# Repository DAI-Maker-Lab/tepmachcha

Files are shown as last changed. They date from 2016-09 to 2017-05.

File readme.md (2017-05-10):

# Tepmachcha

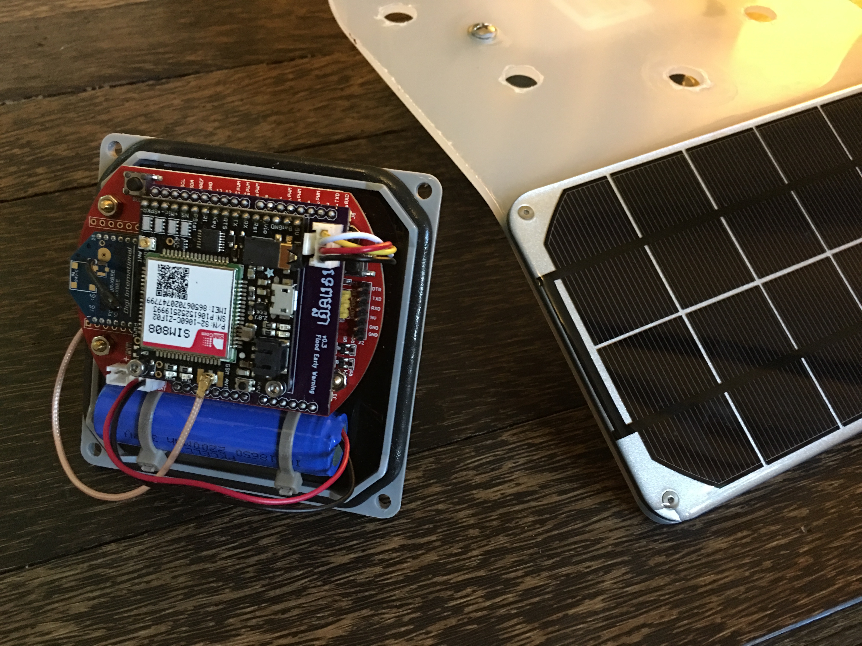
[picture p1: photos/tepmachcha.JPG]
tepmacha


## Flood Early Warning Using Sonar and IVR
Tepmachcha is an open source sonar stream gauge designed to give early warning of flood conditions to residents in vulnerable areas. When a flood condition is detected, Tepmachcha triggers a call with a voice recording via the RapidPro interactive voice response (IVR) system. It also records water levels at regular intervals for later analysis of flooding patterns or to inform more complex hydrological analysis. 

Tepmachcha was designed at the [DAI Maker Lab](http://dai.com/makerlab) in collaboration with [People in Need Cambodia](https://www.clovekvtisni.cz/en/humanitary-aid/country/cambodia) with funding from USAID's [Development Innovations](http://www.development-innovations.org/) project, People in Need, and DAI. It is a fork of the [*Hidrosónico* sonar stream gauge](https://github.com/DAI-Maker-Lab/hidrosonico) piloted by DAI in Honduras as part of the [USAID Proparque](http://en.usaid-proparque.org/) project. It is released under the MIT License.

## Matsya/Tepmachcha
The world-reknowned friezes at Angkor Wat depict scenes from Cambodian history and Hindu mythology, including the [tale of the god Vishnu appearing in the form of a fish to warn mankind of a catastrophic flood](https://en.wikipedia.org/wiki/Matsya). This fish avatar, known in Sanskrit as "Matsya", is called "Tepmachcha" in Khmer, and is the namesake of the project.

## What Tepmachcha Does: The Short Story
Tepmachcha uses sonar to read the level of water in a river, stream, or canal, at regular intervals determined by the user. It uses a cellular data connection to report that level to an internet server. If Tepmachcha detects water level in excess of yellow or red alert limits set by the user, it sends an HTTP POST request that triggers an instance of the RapidPro IVR system to make a voice call that warns users in the affected area(s). Certain operational commands can be sent to the unit by SMS.

## The DAI Maker Lab Design Approach
The DAI Maker Lab leverages emerging tools and approaches associated with the maker movement to build devices and capacity that empower people in developing countries to apply technology to problems. The goal is hardware that can be locally built, repaired, maintained and extended. Toward that end, DAI Maker Lab designs:

* Are always released as open source.
* Utilize off-the-shelf parts when possible.
* Utilize open source hardware when possible, so that discontinuted components can be later recreated or replaced if necessary. 
* Prefer well-documented component hardware, and hardware with an existing community of development and support, to maximize value to end users.
* Prefer transparency to non-expert users over optimal computational or engineering design.

## Hardware
The bill of materials for Tepmachcha includes:

* The [**Seeeduino Stalker v3.0**](http://www.seeedstudio.com/wiki/Seeeduino-Stalker_v3) Arduino-compatible microcontroller board. The Stalker is not the most commonly available Arduino-compatible board, and to be honest, the English documentation -- while much improved over the last year -- is not perfect. But its optimization for low-power operation; inclusion of a solar battery charging circuit, real-time clock (RTC), and XBee socket; and reasonable price make it a good choice for Tepmachcha. 
* The [**Adafruit FONA 808**](https://learn.adafruit.com/adafruit-fona-808-cellular-plus-gps-breakout/overview) cellular breakout board. There are less expensive GSM boards on the market, but Adafruit's standard of documentation, support, and community are difficult to beat. We use the 808 rather than the slightly cheaper 800 because it supports SSL, which RapidPro requires.
* The [**Maxbotix MB7363 HRXL-MaxSonar-WRLS**](http://www.maxbotix.com/Ultrasonic_Sensors/MB7363.htm) sonar. 
* [A simple custom PCB](https://oshpark.com/shared_projects/et6LqUSw) to connect the various parts. This is optional but keeps everything neat and connected inside the enclosure.
* An [**XBee XB24-AWI-001**](http://www.digikey.com/product-detail/en/digi-international/XB24-AWI-001/XB24-AWI-001-ND/935965) radio enables wireless reprogramming in proximity to the unit. Because the units are generally installed in places that are not easy to get to, taking them down and opening them up to flash updated firmware is a real pain. But the XBee can be tempremental; it costs money, uses power and there is a fair amount of code supporting its use, so a non-crazy person might elect to exclude it.
* A **power subsystem**. The Stalker has a charging circuit, but a [LiPo battery](https://www.adafruit.com/products/1781) and a [solar panel](https://www.adafruit.com/products/500) are required; the solar panel will probably have to be spliced onto a [JST-PH 2mm connector](https://www.adafruit.com/products/261) to plug into the Stalker.

The complete bill of materials is included in the repository.

## Libraries
Tepmachcha uses:

* The [Adafruit FONA library](https://github.com/adafruit/Adafruit_FONA_Library).
* [Seeed Studio's DS1337](https://github.com/Seeed-Studio/Sketch_Stalker_V3_1/blob/master/libraries/DS1337/DS1337.h) real time clock library.
* The [Sleep_n0m1](https://github.com/n0m1/Sleep_n0m1) sleep library.
* SoftwareSerial
* Wire

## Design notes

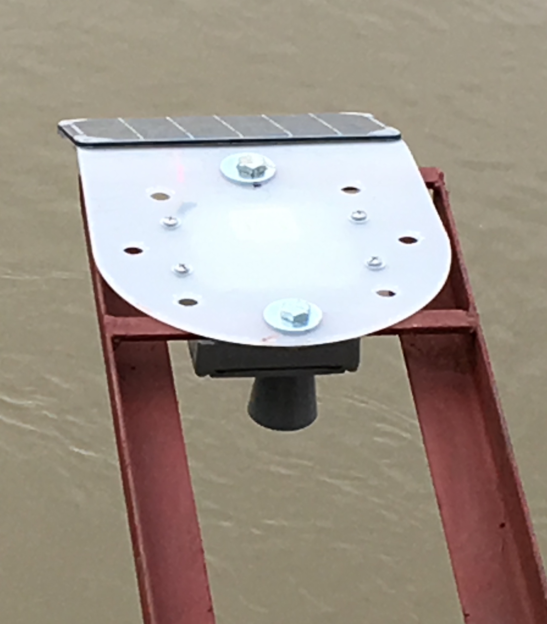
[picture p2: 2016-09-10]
photos/mount_example3.JPG

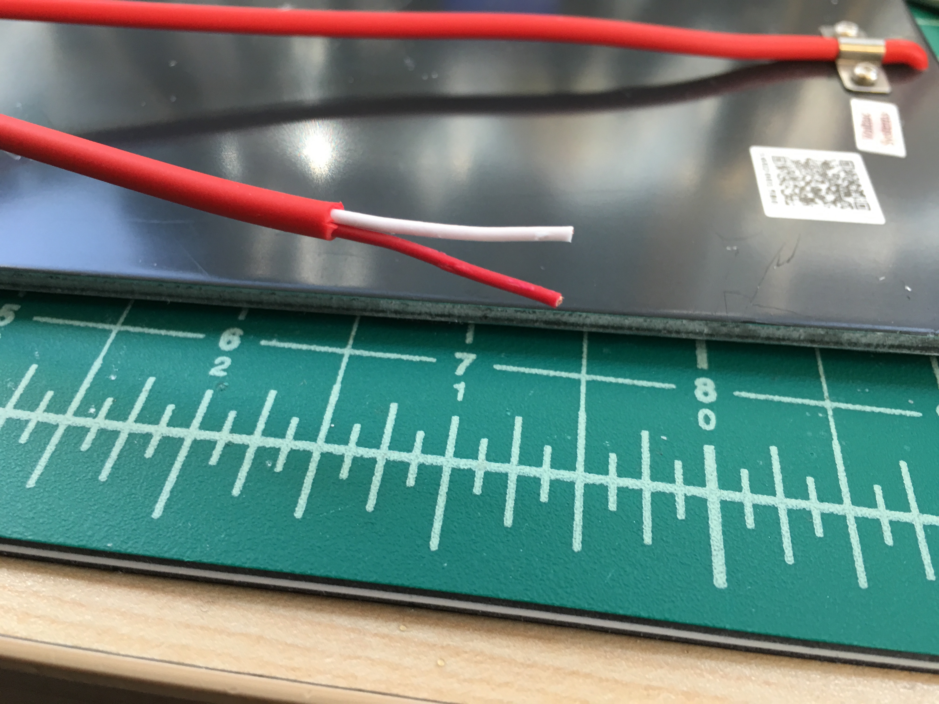
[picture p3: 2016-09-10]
photos/expose_wires.JPG

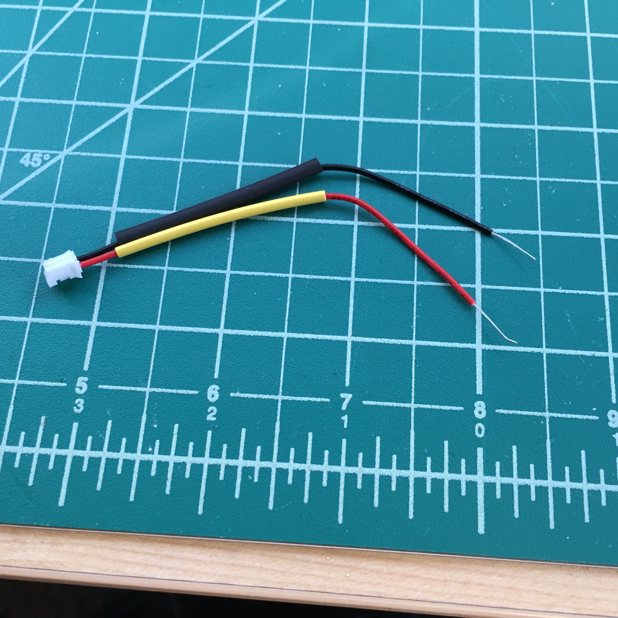
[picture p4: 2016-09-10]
photos/jst.JPG

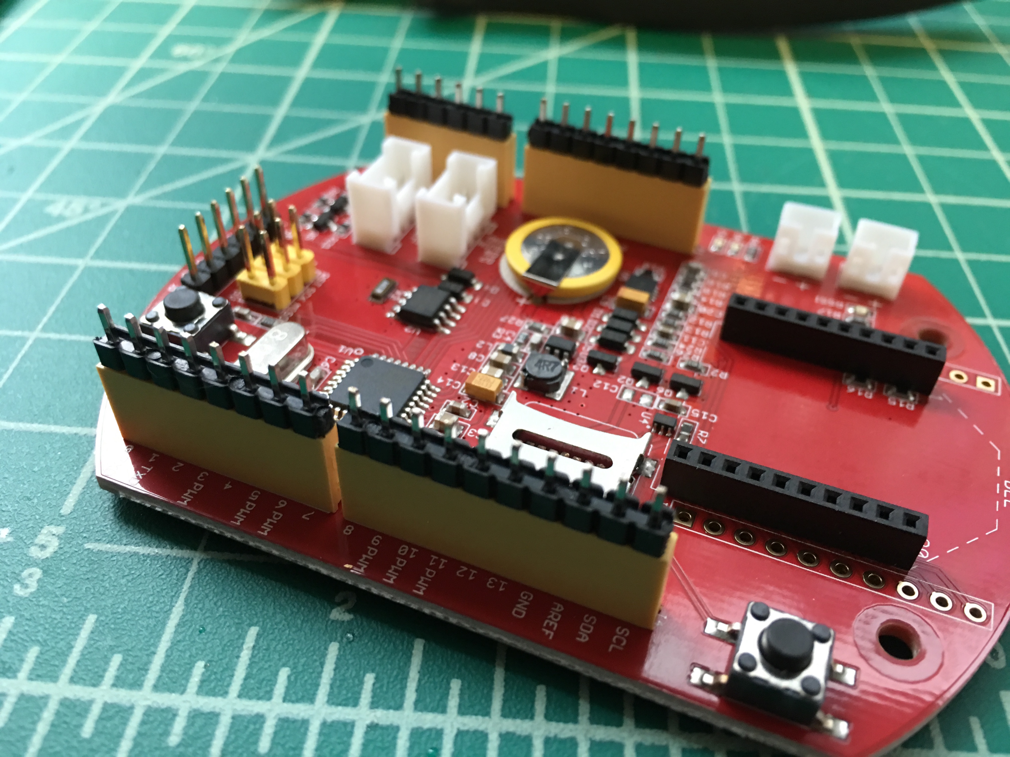
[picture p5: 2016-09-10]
photos/stalker-headers.JPG

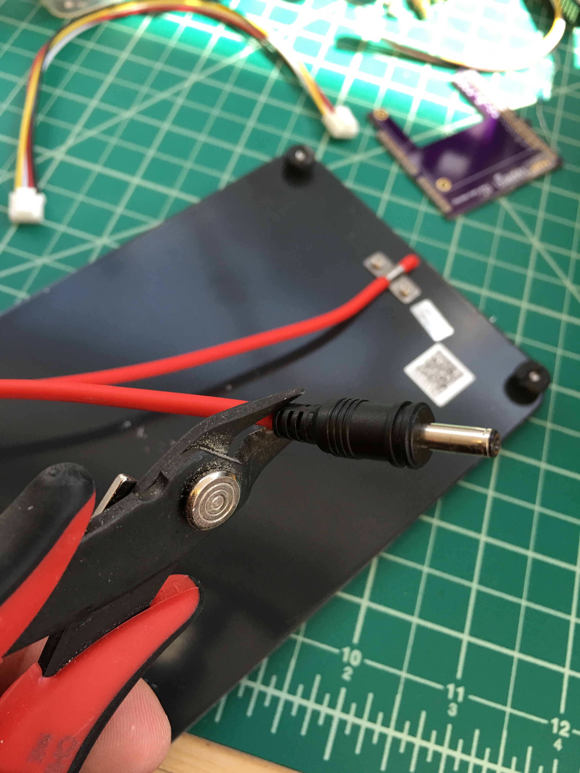
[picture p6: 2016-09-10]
photos/cut_barrel.JPG

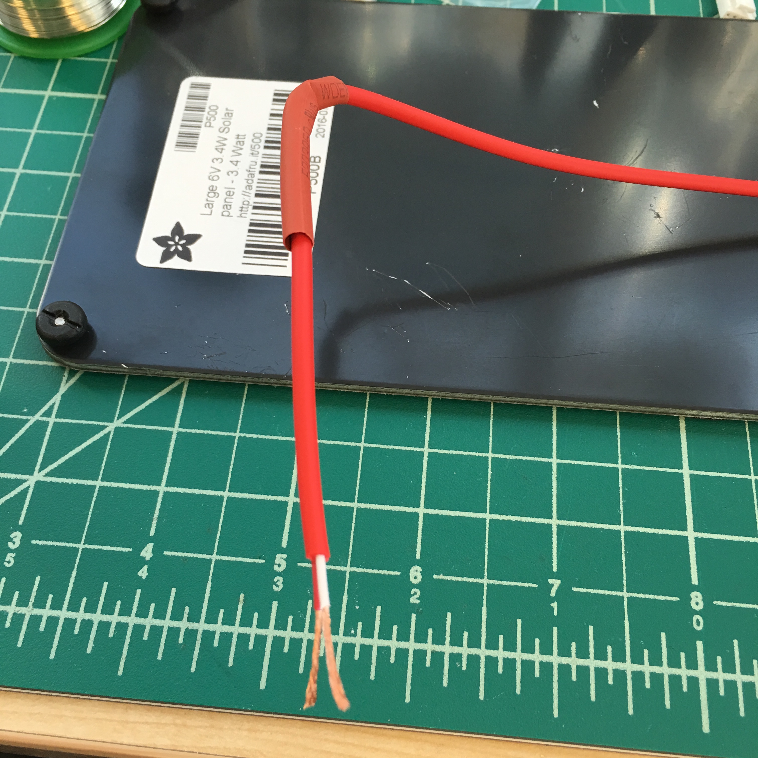
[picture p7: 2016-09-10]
photos/stripped_solar_heatshrink.JPG

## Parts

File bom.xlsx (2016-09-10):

Tepmachcha Bill of Materials
Part | Manufacturer Part Number | Vendor Information | Unit Cost | Pieces per Unit | Total Cost
3D Printed Frame | n/a | Custom (PLA) | $0.36 | 1 | $0.36
Heatshrink tubing | Generic | https://smile.amazon.com/gp/product/B00OZSL8UE | $0.02 | 2 | $0.04
Adafruit FONA 808 uFL | 2542 | https://www.adafruit.com/products/2542 | $49.95 | 1 | $49.95
M2.5 socket cap screw | 91292A012 | http://www.mcmaster.com/mv1472829955/#catalog/91292A012 | $0.05 | 2 | $0.10
Unthreaded spacer for M2.5 screw size | 94669A094 | http://www.mcmaster.com/mv1472829955/#catalog/94669A094 | $0.35 | 2 | $0.70
M2.5 nut | 90591A113 | http://www.mcmaster.com/mv1472829955/#catalog/90591A113 | $0.01 | 2 | $0.02
Carlon 4"x2" PVC junction box | E989NNJ-CAR | http://www.homedepot.com/p/Carlon-4-in-x-2-in-Junction-Box-E989NNJ-CAR/100404097 | $6.88 | 1 | $6.88
Grove 4-pin Female Jumper to Grove 4-pin Conversion Cable | 110990028 | http://www.seeedstudio.com/depot/Grove-4-pin-Female-Jumper-to-Grove-4-pin-Conversion-Cable-5-PCs-per-PAck-p-1020.html | $0.78 | 1 | $0.78
LiPo battery | 1781 | https://www.adafruit.com/products/1781 | $9.95 | 1 | $9.95
Maxbotix Sonar | MB7363 HRXL-MaxSonar-WRM | http://www.maxbotix.com/Ultrasonic_Sensors/MB7363.htm | $119.95 | 1 | $119.95
Mini GSM/Cellular Quad-Band Antenna - 2dBi SMA Plug | 1859 | https://www.adafruit.com/products/1859 | $4.95 | 1 | $4.95
PCB | n/a | Custom (OSH Park) | $6.60 | 1 | $6.60
Scotch Heavy Duty Fasteners | RFD7091 | http://smile.amazon.com/gp/product/B00347A8GM?psc=1&redirect=true&ref_=oh_aui_detailpage_o00_s00 | $2.71 | 1 | $2.71
Seeed Studio Seeeduino Stalker v3 | 102010017 | http://www.seeedstudio.com/depot/Seeeduino-Stalker-v3-p-1882.html?cPath=6_7 | $39.00 | 1 | $39.00
SMA to uFL/u.FL/IPX/IPEX RF Adapter Cable | 851 | https://www.adafruit.com/products/851 | $3.95 | 1 | $3.95
Solar panel (6V 3.4W) | 500 | https://www.adafruit.com/products/500 | $39.00 | 1 | $39.00
JST PH-2 connector | 261 | https://www.adafruit.com/products/261 | $0.75 | 1 | $0.75
Solar panel mount | n/a | Custom (polypropylene) |  | 1 | $0.00
Xbee 802.15.4 1MW w/wire antenna | XB24-AWI-001 | http://www.digikey.com/product-detail/en/XB24-AWI-001/XB24-AWI-001-ND/935965 | $19.00 | 1 | $19.00
Grand Total |  |  |  |  | $304.69

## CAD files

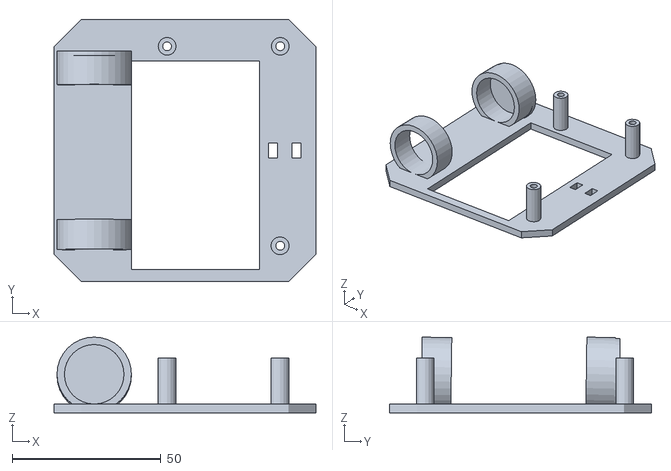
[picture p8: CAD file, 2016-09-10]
laser-stl/interior_mount_3D.stl
88.0 x 88.0 x 25.5

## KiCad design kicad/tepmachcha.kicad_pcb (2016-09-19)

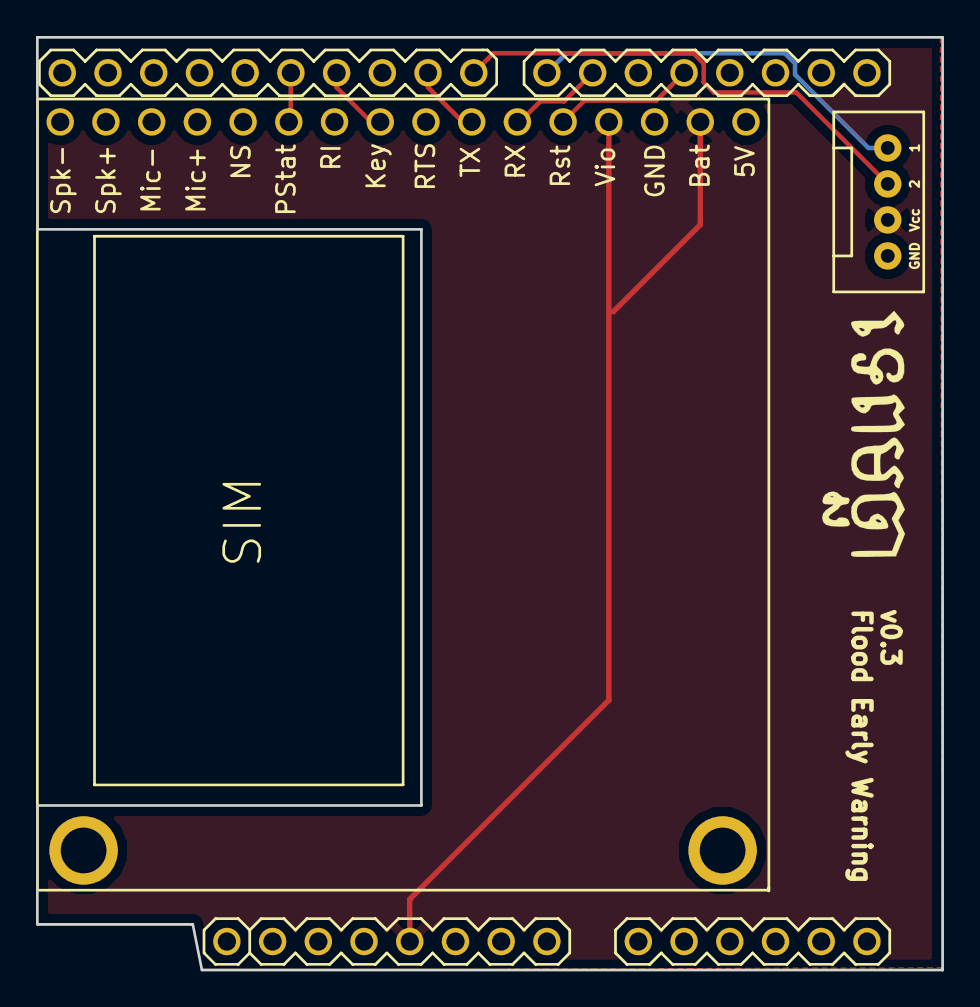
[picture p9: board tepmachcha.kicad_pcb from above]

Board: 2 copper layers, 50.3 x 51.8 mm, 3 parts (0 on the bottom side), 9 nets.

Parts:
P1: CONN_01X04; Grove_straight
SHIELD1: ARDUINO_SHIELD; ARDUINO
U1: FONA_808

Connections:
GND: P1.4, SHIELD1.GND1, U1.3
unnamed: P1.1, SHIELD1.7
unnamed: P1.2, SHIELD1.8
unnamed: SHIELD1.4, U1.5
unnamed: SHIELD1.6, U1.6
unnamed: SHIELD1.9, U1.7
unnamed: SHIELD1.11, U1.9
unnamed: SHIELD1.12, U1.11
VCC: P1.3, SHIELD1.5V, U1.2, U1.4

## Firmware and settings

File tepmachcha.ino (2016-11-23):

#define VERSION "1.03"      //  Version number

//  Customize these items for each installation
// - - - - - - - - - - - - - - - - - - - - - - - - - - - - - - - - - - - - - - - 
#define PUBLIC_KEY "YOUR_PUBLIC_KEY"      //  Public key for phant stream
#define PRIVATE_KEY "YOUR_PRIVATE_KEY"    //  Private key for phant stream
#define APITOKEN "YOUR_RAPIDPRO_API_TOKEN"  //  Rapidpro API token
#define TARGETCONTACT "TARGET_CONTACT_UUID" //  Rapidpro needs at least a dummy contact 
                                            //  to start a flow
#define SENSOR_HEIGHT 100   //  Height of top of octagonal gasket from streambed, in cm
#define UTCOFFSET 0         //  Local standard time variance from UTC
#define XBEEWINDOWSTART 14  //  Hour to turn on XBee for programming window
#define XBEEWINDOWEND 17    //  Hour to turn off XBee
#define INTERVAL 15         //  Number of minutes between readings
#define BEEPASSWORD "XBEE_PASSWORD"  //  Password to turn on XBee by SMS
#define CLEARYELLOW "CLEAR_YELLOW_PASSSWORD" //  Password to clear yellow alerts
#define CLEARRED "CLEAR_RED_PASSWORD"        //  Password to clear red alerts

/*   Tepmachcha is written to accommodate different alert levels for separate zones --
 *   a low-lying zone in the region might need a lower yellow alert level than another
 *   zone. Note that using more than three zones will cause an overflow in the SMS
 *   reply function as currently written.
 */
#define ZONES 2             //  Number of separate zones to be covered

/*   If you do not define yellow, red, yellowFlow, redFlow and alert for all of your zones, 
 *   weird things will happen. Don't forget that zones will be numbered starting from zero.
 */
 
const int yellow[ZONES] = {550, 500};        //  Yellow alert level for Zones 0 & 1
const int red[ZONES] = {600, 550};           //  Red alert level for Zones 0 & 1
const char* yellowFlow[ZONES] = {"RAPIDPRO_YELLOWALERT_FLOW_UUID_ZONE_0", "RAPIDPRO_YELLOWALERT_FLOW_UUID_ZONE_1"};
const char* redFlow[ZONES] = {"RAPIDPRO_REDALERT_FLOW_UUID_ZONE_0", "RAPIDPRO_REDALERT_FLOW_UUID_ZONE_1"};
char alert[ZONES] = {'G', 'G'};              //  Green, yellow, or red alert state (G, Y, R)
boolean sendYellow[ZONES] = {false, false};
boolean sendRed[ZONES] = {false, false};

// - - - - - - - - - - - - - - - - - - - - - - - - - - - - - - - - - - - - - - - 

#include <Adafruit_FONA.h>
#include <DS1337.h>           //  For the Stalker's real-time clock (RTC)
#include <Sleep_n0m1.h>       //  Sleep library
#include <SoftwareSerial.h>   //  For serial communication with FONA
#include <Wire.h>             //  I2C library for communication with RTC

#define RTCINT 0    //  RTC interrupt number
#define RTCPIN 2    //  Onboard Stalker RTC pin
#define FONA_RST 4  //  FONA RST pin
#define BEEPIN 5    //  XBee power pin
#define FONA_RX 6   //  UART pin into FONA
#define PING 7      //  Sonar ping pin
#define RANGE 8     //  Sonar range pin -- pull low to turn off sonar
#define FONA_TX 9   //  UART pin from FONA
#define FONA_KEY 11 //  FONA Key pin
#define FONA_PS 12  //  FONA power status pin

boolean sentData = false;
boolean smsPower = false;       //  Manual XBee power flag
boolean noSMS = false;          //  Flag to turn off SMS checking -- for future use
boolean timeReset = false;      //  Flag indicating whether midnight time reset has already occurred
byte beeShutoffHour = 0;        //  Hour to turn off manual power to XBee
byte beeShutoffMinute = 0;      //  Minute to turn off manual power to XBee
char method = 0;                //  Method of clock set, for debugging

DateTime now;

SoftwareSerial fonaSerial = SoftwareSerial (FONA_TX, FONA_RX);
Adafruit_FONA fona = Adafruit_FONA (FONA_RST);

DS1337 RTC;         //  Create the DS1337 real-time clock (RTC) object
Sleep sleep;        //  Create the sleep object



static void rtcIRQ()
{
        RTC.clearINTStatus();   //  Wake from sleep and clear the RTC interrupt
}



void setup()
{
        Wire.begin(); //  Begin the I2C interface
        RTC.begin();  //  Begin the RTC        
        Serial.begin (57600);
        Serial.print (F("Tepmachcha version "));
        Serial.print (VERSION);
        Serial.print (F(" "));
        Serial.print (__DATE__);    //  Compile data and time helps identify software uploads
        Serial.print (F(" "));
        Serial.println (__TIME__);

        analogReference (INTERNAL); 

        Serial.print (F("Startup voltage "));
        Serial.println (analogRead (A7) * 6.4);   //  Convert ADC reading to voltage
        
        pinMode (BEEPIN, OUTPUT);
        pinMode (RANGE, OUTPUT);
        pinMode (FONA_KEY, OUTPUT);
        pinMode (FONA_RX, OUTPUT);

        /*   If the voltage at startup is less than 3.5V, we assume the battery died in the field
         *   and the unit is attempting to restart after the panel charged the battery enough to
         *   do so. However, running the unit with a low charge is likely to just discharge the
         *   battery again, and we will never get enough charge to resume operation. So while the
         *   measured voltage is less than 3.5V, we will put the unit to sleep and wake once per 
         *   hour to check the charge status.
         */

        while (analogRead (A7) < 547)   
        {
                Serial.println (F("Sleeping to save power..."));
                Serial.flush();
                digitalWrite (BEEPIN, HIGH);      //  Make sure XBee is powered off
                digitalWrite (RANGE, LOW);        //  Make sure sonar is off
                RTC.enableInterrupts (EveryHour); //  We'll wake up once an hour
                RTC.clearINTStatus();             //  Clear any outstanding interrupts
                attachInterrupt (RTCINT, rtcIRQ, FALLING);
                interrupts();
                sleep.pwrDownMode();                    //  Set sleep mode to Power Down
                sleep.sleepInterrupt (RTCINT, FALLING); //  Sleep; wake on falling voltage on RTC pin
        }

        digitalWrite (RANGE, HIGH);          //  If set low, sonar will not range
        digitalWrite (FONA_KEY, HIGH);       //  Initial state for key pin

        //  We will use the FONA to get the current time to set the Stalker's RTC
        fonaOn();
        clockSet();
        
        //  Delete any accumulated SMS messages to avoid interference from old commands
        fona.sendCheckReply (F("AT+CMGF=1"), F("OK"));            //  Enter text mode
        fona.sendCheckReply (F("AT+CMGDA=\"DEL ALL\""), F("OK")); //  Delete all SMS messages
        
        fonaOff();
        
        RTC.enableInterrupts (EveryMinute);  //  RTC will interrupt every minute
        RTC.clearINTStatus();                //  Clear any outstanding interrupts
        attachInterrupt (RTCINT, rtcIRQ, FALLING);
        interrupts();

        now = RTC.now();    //  Get the current time from the RTC
        
        //  We'll keep the XBee on for an hour after startup to assist installation
        if (now.hour() == 23)
        {
                beeShutoffHour = 0;
        }
        else
        {
                beeShutoffHour = (now.hour() + 1);
        }
        beeShutoffMinute = now.minute();

        Serial.print (F("XBee powered on until at least "));
        Serial.print (beeShutoffHour);
        Serial.print (F(":"));
        Serial.println (beeShutoffMinute);
        Serial.flush();
        smsPower = true;
}



void loop()
{
        now = RTC.now();      //  Get the current time from the RTC

        Serial.print (now.hour());
        Serial.print (F(":"));
        Serial.println (now.minute());

        int streamHeight = takeReading();

        /*  One failure mode of the sonar -- if, for example, it is not getting enough power -- 
        is to return the minimum distance the sonar can detect; in the case of the 10m sonars
        this is 50cm. This is also what would happen if something were to block the unit -- a
        plastic bag that blew onto the enclosure, for example. We very much want to avoid false
        positive alerts, so for the purposes of yellow and red alerts, we will ignore anything
        less than 55cm from the sensor. 
        
        Per discussions with PIN, alerts will be cleared manually, by sending an SMS to the 
        unit. */

        //  Cycle through zones to check for new yellow alerts

        for (int i = 0; i < ZONES; i++)
        {
                if (streamHeight >= yellow[i] && streamHeight < (SENSOR_HEIGHT - 55) && alert[i] == 'G')
                {
                        if (validate (yellow[i] == true))
                        {
                                sendYellow[i] = true;
                                alert[i] = 'Y';
                                upload (streamHeight);
                        }
                }
        }

        //  Do the same for red alerts

        for (int i = 0; i < ZONES; i++)
        {
                if (streamHeight >= red[i] && streamHeight < (SENSOR_HEIGHT - 55) && alert[i] != 'R')
                {
                        if (validate (red[i] == true))
                        {
                                sendRed[i] = true;
                                alert[i] = 'R';
                                upload (streamHeight);
                        }
                }
        }
        
        if (now.minute() % INTERVAL == 0 && sentData == false)   //  If it is time to send a scheduled reading...
        {
                upload (streamHeight);
        }
        else
        {
                sentData = false;
        }

        //  We will turn on the XBee radio for programming only within a specific
        //  window to save power
        if (now.hour() >= XBEEWINDOWSTART && now.hour() <= XBEEWINDOWEND)
        {
                digitalWrite (BEEPIN, LOW);
        }
        else
        {
                //  If the XBee power was turned on by SMS, we'll check to see if 
                //  it's time to turn it back off
                if(smsPower == true && now.hour() < beeShutoffHour)
                {
                        digitalWrite (BEEPIN, LOW);
                }
                else
                {
                        if(smsPower == true && now.hour() == beeShutoffHour && now.minute() < beeShutoffMinute)
                        {
                                digitalWrite (BEEPIN, LOW);
                        }
                        else
                        {
                                if (smsPower == true && now.hour() == 23 && beeShutoffHour == 0)
                                {
                                        digitalWrite (BEEPIN, LOW);
                                }
                                else
                                {
                                        if (smsPower == true)
                                        {
                                                  Serial.println (F("Turning XBee off..."));
                                                  Serial.flush();
                                                  wait (500);
                                        }
        
                                        digitalWrite (BEEPIN, HIGH);
                                        smsPower = false;
                                }
                        }
                }
        }

        Serial.flush();                         //  Flush any output before sleep

        sleep.pwrDownMode();                    //  Set sleep mode to "Power Down"
        RTC.clearINTStatus();                   //  Clear any outstanding RTC interrupts
        sleep.sleepInterrupt (RTCINT, FALLING); //  Sleep; wake on falling voltage on RTC pin
}



void upload (int streamHeight)
{
        fonaOn();
        sendReading (streamHeight);

        for (int i = 0; i < ZONES; i++)
        {
                if (sendYellow[i] == true)
                {
                        Serial.print (F("Triggering yellow alert for Zone "));
                        Serial.println (i);
                        if (ivr (yellowFlow[i]) == false) //  If it doesn't work...
                        {
                                Serial.println (F("Trigger appeared to fail. Will retry in 90 seconds..."));
                                wait (90000);         //  ...wait 90 seconds...
                                ivr (yellowFlow[i]);  //  ...and try again.
                                /*   We could try repeatedly; the worry is that if
                                 *   the trigger appeared to fail on our end but
                                 *   the flow really was triggered, we could end
                                 *   up sending many messages to subscribers. 
                                 *   
                                 *   Trying twice strikes a balance between making
                                 *   sure the message went out and avoiding the
                                 *   system being seen as a nuisance.
                                 */
                        }
                        sendYellow[i] = false;
                }

                if (sendRed[i] == true)
                {
                        Serial.print (F("Triggering red alert for Zone "));
                        Serial.println (i);
                        if (ivr (redFlow[i]) == false)
                        {
                                Serial.println (F("Trigger appeared to fail. Will retry in 90 seconds..."));
                                wait (90000);
                                ivr (redFlow[i]);
                        }
                        sendRed[i] = false;
                }
        }
        
        if (noSMS == false)
        {
                checkSMS();
        }

        /*   The RTC drifts more than the datasheet says, so we'll reset the time every day at
         *   midnight. 
         */
        if (now.hour() == 0 && timeReset == false)
        {
                clockSet();
                timeReset = true;
        }

        if (now.hour() != 0)
        {
                timeReset = false;
        }
        
        fonaOff();

        sentData = true;
}



void wait (unsigned long period)
{
        //  Non-blocking delay function
        unsigned long waitend = millis() + period;
        while (millis() <= waitend)
        {
                Serial.flush();
        }
}



boolean fonaOn()
{
        if (digitalRead (FONA_PS) == LOW)             //  If the FONA is off...
        {
                Serial.print (F("Powering FONA on..."));
                while (digitalRead (FONA_PS) == LOW) 
                {
                        digitalWrite(FONA_KEY, LOW);  //  ...pulse the Key pin low...
                        wait (500);
                }
                digitalWrite (FONA_KEY, HIGH);        //  ...and then return it to high
                Serial.println(F(" done."));
        }
        
        Serial.println (F("Initializing FONA..."));
        
        fonaSerial.begin (4800);                      //  Open a serial interface to FONA
        
        if (fona.begin (fonaSerial) == false)         //  Start the FONA on serial interface
        {
                Serial.println (F("FONA not found. Check wiring and power."));
                return false;
        }
        else
        {
                Serial.print (F("FONA online. "));
                
                unsigned long gsmTimeout = millis() + 30000;
                boolean gsmTimedOut = false;

                Serial.print (F("Waiting for GSM network... "));
                while (1)
                {
                        byte network_status = fona.getNetworkStatus();
                        if(network_status == 1 || network_status == 5) break;
                        
                        if(millis() >= gsmTimeout)
                        {
                                gsmTimedOut = true;
                                break;
                        }
                        
                        wait (250);
                }

                if(gsmTimedOut == true)
                {
                        Serial.println (F("timed out. Check SIM card, antenna, and signal."));
                        return false;
                }
                else
                {
                        Serial.println(F("done."));
                }

                //  RSSI is a measure of signal strength -- higher is better; less than 10 is worrying
                byte rssi = fona.getRSSI();
                Serial.print (F("RSSI: "));
                Serial.println (rssi);

                wait (3000);    //  Give the network a moment

                //fona.setGPRSNetworkSettings (F("cellcard"));    //  Set APN to your local carrier

                if (rssi > 5)
                {
                        if (fona.enableGPRS (true) == false);
                        {
                              //  Sometimes enableGPRS() returns false even though it succeeded
                              if (fona.GPRSstate() != 1)
                              {
                                      for (byte GPRSattempts = 0; GPRSattempts < 5; GPRSattempts++)
                                      {
                                            Serial.println (F("Trying again..."));
                                            wait (2000);
                                            fona.enableGPRS (true);
                                            
                                            if (fona.GPRSstate() == 1)
                                            {
                                                    Serial.println (F("GPRS is on."));
                                                    break;
                                            }
                                            else
                                            {
                                                    Serial.print (F("Failed to turn GPRS on... "));
                                            }
                                      }
                              }
                        }
                }
                else
                {
                        Serial.println (F("Can't transmit, network signal strength is poor."));
                        gsmTimedOut = true;
                }
                
                return true;
        }
}
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

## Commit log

2016-09-10 Add files via upload
    Initial commit
    [bom.xlsx, interior_mount_3D.stl]
2016-09-19 Added kicad and Gerber files
    [tepmachcha-B.Cu.gbl, tepmachcha-B.Mask.gbs, tepmachcha-B.SilkS.gbo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]
2016-11-23 Fixed smsPower anomaly
    When an smsPower command was issued between 23:00 and 0:00, the XBee would shut off anyway because 23 > 0.
    [tepmachcha.ino]
